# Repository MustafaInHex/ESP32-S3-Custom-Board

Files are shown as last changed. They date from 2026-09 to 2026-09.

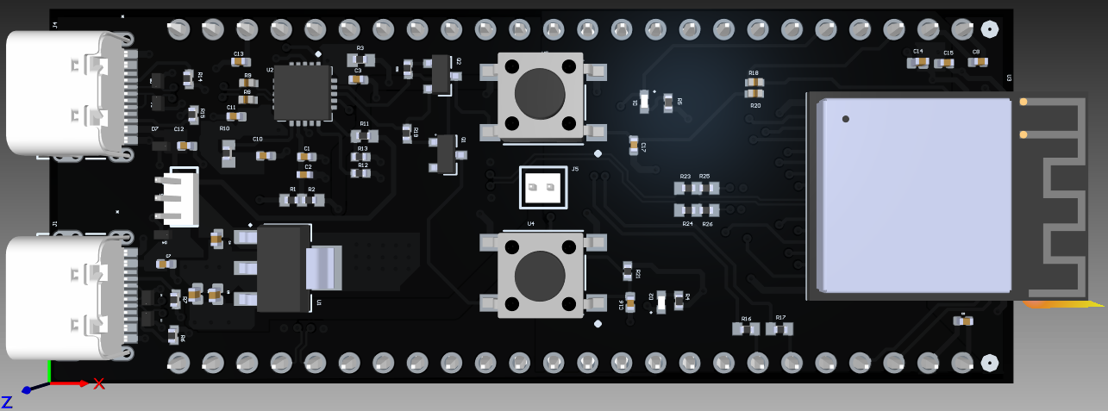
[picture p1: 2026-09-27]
TOP.png

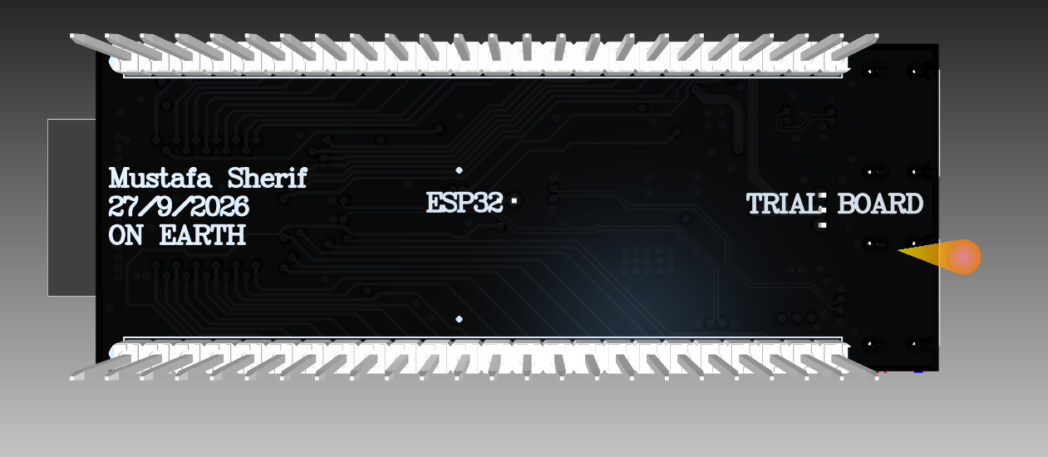
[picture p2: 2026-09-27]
BOTTOM.png

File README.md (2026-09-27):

# ESP32-S3 Dual USB-C Development Board

This repository contains a complete Altium Designer hardware project for a custom ESP32-S3 Mini development board. The design focuses on robust USB connectivity, safe power handling, and standard layout techniques for microcontroller applications.

## Hardware Specifications & Features
* **Microcontroller:** ESP32-S3 Mini module.
* **Dual USB-C Interfaces:**
  * **Port 1 (UART):** Routed through an onboard FTDI USB-to-UART bridge for direct programming, flashing, and serial debugging. Includes auto-reset circuitry using a standard DTR/RTS transistor configuration.
  * **Port 2 (Native):** Direct native USB connection to the ESP32-S3 data pins.
* **Power Management:** Onboard 5V to 3.3V LDO regulation with jumper-selectable routing to easily isolate or select power sources during testing.
* **Signal Integrity & Protection:** Differential pairs for USB data lines are routed for 90Ω impedance. Both USB-C ports feature integrated ESD protection arrays to shield the ICs from voltage spikes.
* **User Interface:** Dedicated tactile switches for Boot and Reset, alongside independent Power and User-programmable status LEDs.
* **Aesthetics:** Custom exposed-copper ENIG (gold) logo implemented via precise solder mask cutouts on the top layer.

## Repository Structure
* **`Altium_Project/`**: Source files including the main project file (`.PrjPcb`), Schematics (`.SchDoc`), PCB Layout (`.PcbDoc`), and Custom Component Libraries (`.SchLib`, `.PcbLib`).
* **`Manufacturing_Outputs/`**: Production-ready `.zip` containing Gerber and NC Drill files, Pick and Place assembly data (`.csv`), and the full Bill of Materials (BOM).
* **`Datasheets/`**: Core technical reference documents, including the ESP32-S3 module datasheet.
* **`3D_Models/`**: STEP files used for the component bodies to ensure accurate 3D visualization and mechanical clearance checking.
* **`Schematic.pdf`**: A high-resolution PDF export of the circuit schematic for immediate browser viewing without requiring Altium Designer.

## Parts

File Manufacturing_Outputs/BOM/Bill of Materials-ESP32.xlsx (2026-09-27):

Description | Designator | Quantity | Manufacturer_Name | Manufacturer_Part_Number | Comment | Footprint
CAP CER 0.1UF 50V X7R 0402 SMD | C1, C3, C7, C8, C9, C10, C11, C12, C13, C15, C17 | 11 |  |  | 100n | CAPC1005X55N
16V 4.7uF X5R 卤20% 0402 Multilayer Ceramic Capacitors MLCC - SMD/SMT ROHS | C2, C4 | 2 |  |  | 4.7U | CAPC1005X70N
CL05A106MP8NUB8-CAP CER 10UF 10V X5R 0402 SMD, CAP CER 10UF 10V X5R 0402 SMD | C5, C6, C14 | 3 |  |  | 10u | CAPC1005X90N
35V 1uF X5R 卤10% 0402 Multilayer Ceramic Capacitors MLCC - SMD/SMT ROHS | C16 | 1 |  |  | 1UF | CAPC1005X65N
LED, GREEN, 60MCD, 573NM, 0402; LED Colour:Green; LED Mounting:SMD; Forward Current If:20mA; Forward Voltage:2V; Wavelength Typ:573nm; Luminous Intensity:60mcd; Viewing Angle:120Â°; Lens Shape:Rectangular; Product Range:WL-SMCC Series; Automotive Qualific | D1, D2 | 2 |  |  | WL-SMCC_0402 | WL-SMCC_0402
TVS DIODE 12VC 3A SOD882 / ESD Suppressor TVS Bi-Dir 5.3V Automotive 2-Pin SOD-882 T/R | D3, D4, D5, D6, D7, D8 | 6 | Littelfuse Inc | AQ3045-01ETG | AQ3045-01ETG | TVS_SOD882_LTF
USB Connector, 16 Contact(s), Female, Right Angle, Surface Mount Terminal, Locking, Receptacle | J1, J4 | 2 |  |  | USBC-2171790001 | USBC-2171790001
KK 254 Breakaway Header, Vertical, 24 Circuits, 0.38µm Gold (Au) Plating, Mating Pin Length 7.49mm, Bag | J2, J3 | 2 |  |  | 22284245 | CONN_SD-42375-001_M295_24_MOL
Pin Header, Board-to-Board, 1.27 mm, 1 Rows, 2 Contacts, Through Hole Straight, FTS Series | J5 | 1 |  |  | SAMTEC-FTS-102-01-X-SJ | SAMTEC-FTS-102-01-X-S
SAMTEC-FTS-103-01-X-S Connector Header Surface Mount 3 position 0.050 (1.27mm) | J6 | 1 |  |  | SAMTEC-FTS-103-01-X-S | SAMTEC-FTS-103-01-X-S
Jumper (Busbar), Jumper Socket, Pin Hdrs; |Harwin M50-1920005 | LINK1, LINK2 | 2 |  |  | Connector header
TRANS NPN 25V 1.5A SOT23-3 / Bipolar (BJT) Transistor NPN 25 V 1.5 A 100MHz 300 mW Surface Mount SOT-23-3 | Q1, Q2 | 2 |  |  | SS8050-G | TRANS_SS8050-G
0 Ohms Jumper 0.063W, 1/16W Chip Resistor 0402 (1005 Metric) Moisture Resistant Thick Film RC0402JR-070RL | R1, R2, R3, R10, R16, R17, R23, R24, R25, R26 | 10 |  |  | 0R | RESC1005X40
1 kOhms Â±1% 0.063W, 1/16W Chip Resistor 0402 (1005 Metric) Moisture Resistant Thick Film | R4, R5 | 2 |  |  | 1K | RESC1005X40N
5.1 kOhms ±1% 0.063W, 1/16W Chip Resistor 0402 (1005 Metric) Automotive AEC-Q200, Moisture Resistant Thick Film | R6, R7, R14, R15 | 4 |  |  | AC0402FR-075K1L | 5k1
62.5mW Thick Film Resistors 50V ±100ppm/℃ ±1% 27Ω 0402 Chip Resistor - Surface Mount ROHS | R8, R9, R18, R20 | 4 | Yageo | RC0402FR-0727RL | 27R | RES_RC0402_YAG
4.7 kOhms ±1% 0.063W, 1/16W Chip Resistor 0402 (1005 Metric) Moisture Resistant Thick Film | R11 | 1 |  |  | 4K7 | RESC1005X40 - duplicate
Res Thick Film 0402 10K Ohm 1% 0.063W(1/16W) ±100ppm/C Pad SMD T/R Automotive AEC-Q200 | R12, R13, R19, R21, R22 | 5 |  |  | 10K | RESC1005X37N
1.5-A, 20-V, low-dropout voltage regulator with reverse current & reverse voltage protection | U1 | 1 |  |  | TL1963A-33DCYR | VREG_TL1963A-33DCYR
IC USB SERIAL FULL UART 20QFN | U2 | 1 |  |  | FT231XQ-R | QFN50P400X400X80-21N
ESP32-S3-MINI-1-N8 RF TXRX MOD BT WIFI PCB TH SMD | U3 | 1 |  |  | ESP32-S3-MINI-1-N8 | ESP32-S3-MINI-1-N8
Switch Tactile N.O SPST Round Button Gull Wing 0.05A 12VDC 100000Cycle 1.57N SMD T/R | U4, U5 | 2 | C&K Components | PTS645SM43SMTR92LFS | PTS645SM43SMTR92LFS | SWITCH_43SMTR92LFS

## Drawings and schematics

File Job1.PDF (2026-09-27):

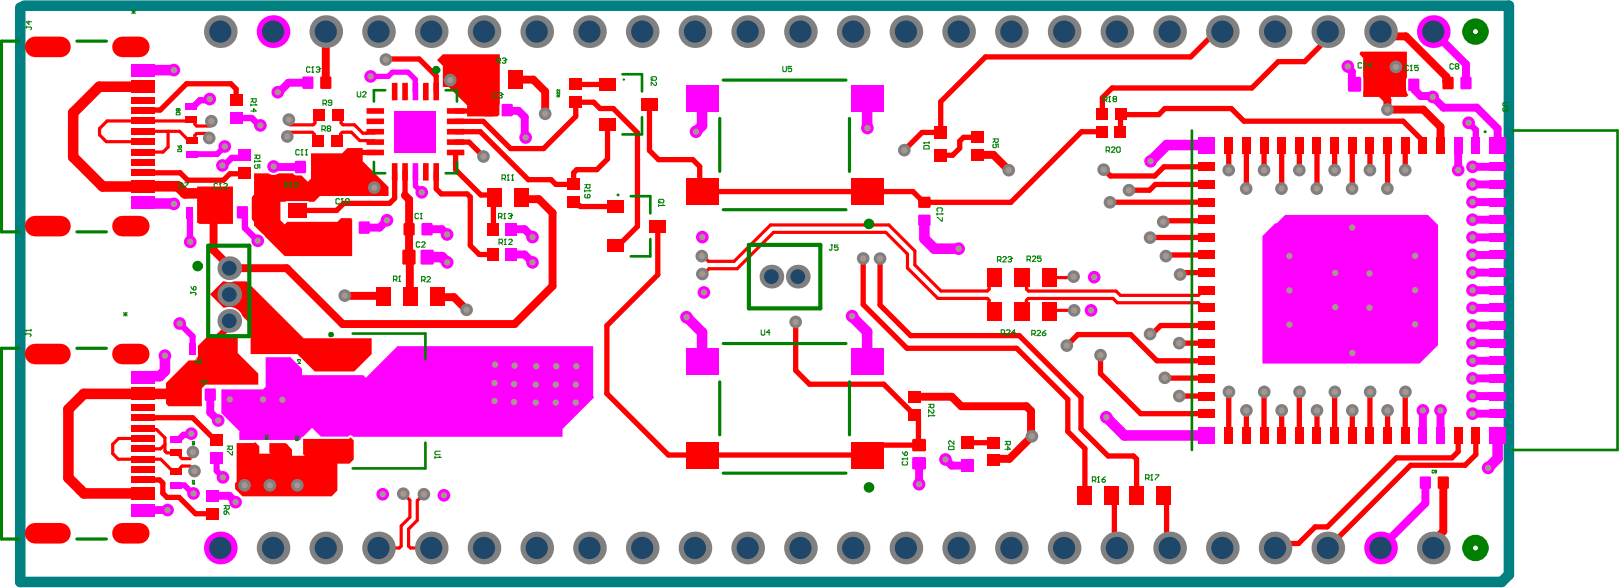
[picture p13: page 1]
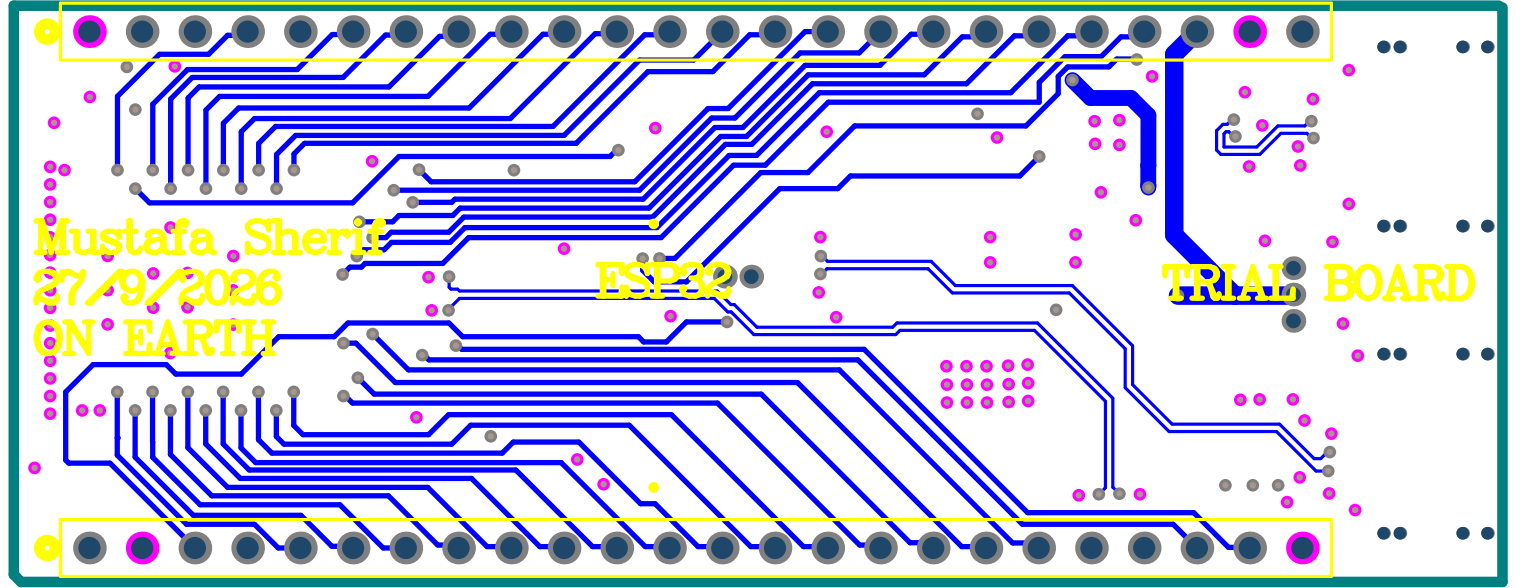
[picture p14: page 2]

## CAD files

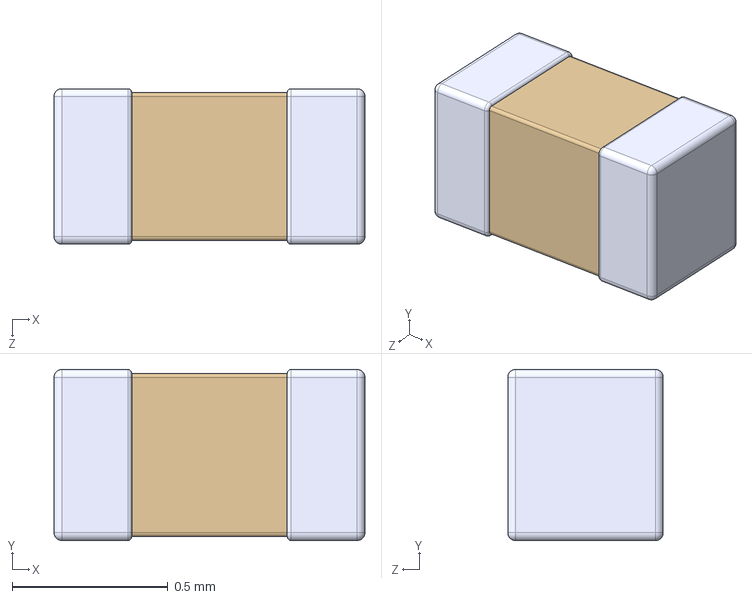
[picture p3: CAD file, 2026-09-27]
3D/CL05B104KB54PNC.STEP
1.00 x 0.55 x 0.5 mm

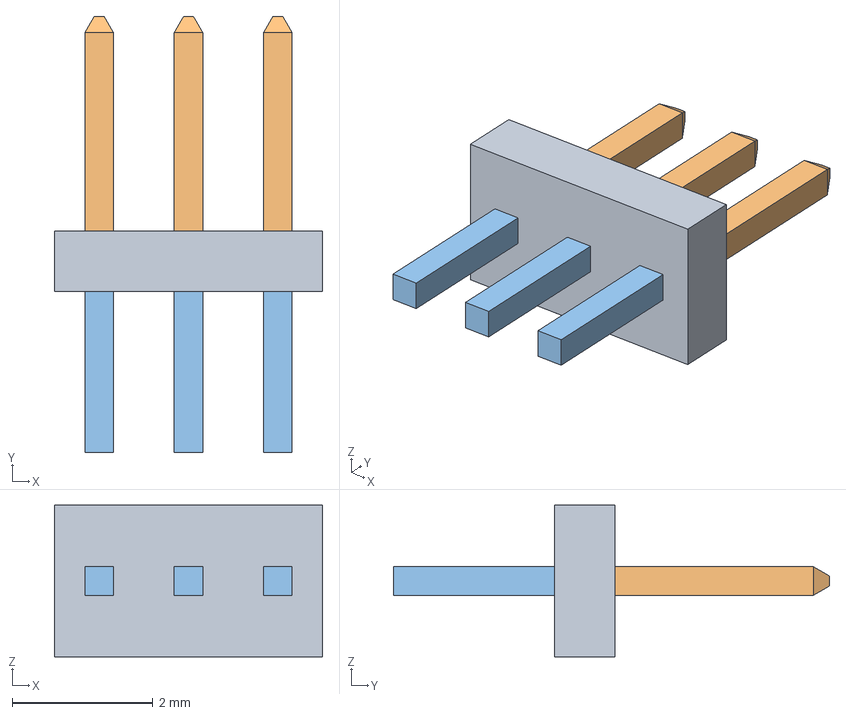
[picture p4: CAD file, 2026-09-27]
3D/FTS-103-01-F-S.stp
3.81 x 6.20 x 2.16 mm
FTS-103-01-F-S_body
FTS-103-01-F-S_pins1
FTS-103-01-F-S_pins2

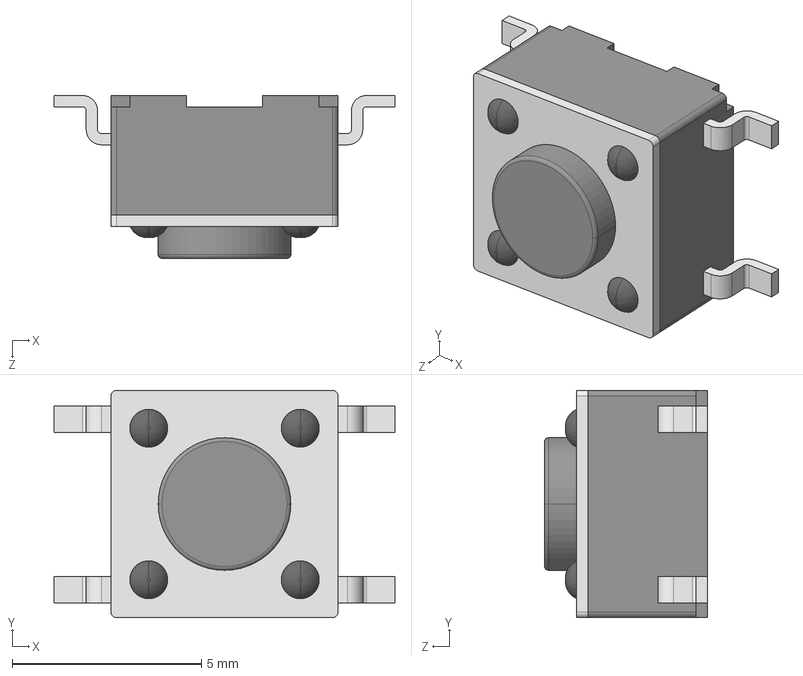
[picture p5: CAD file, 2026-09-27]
3D/PTS645SM43SMTR92LFS.stp
9.00 x 6.00 x 4.30 mm

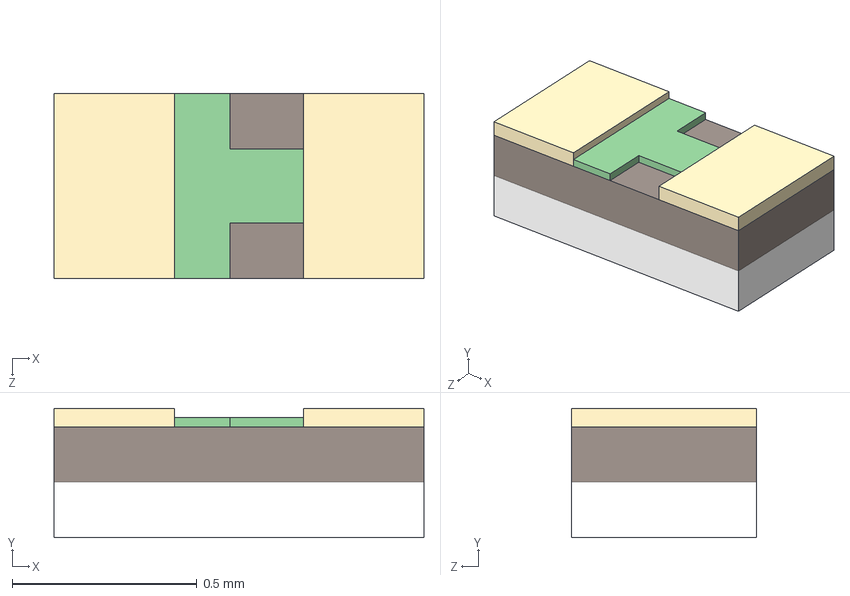
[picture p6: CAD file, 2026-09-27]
3D/VLMG1500-GS08.stp
1.00 x 0.35 x 0.5 mm

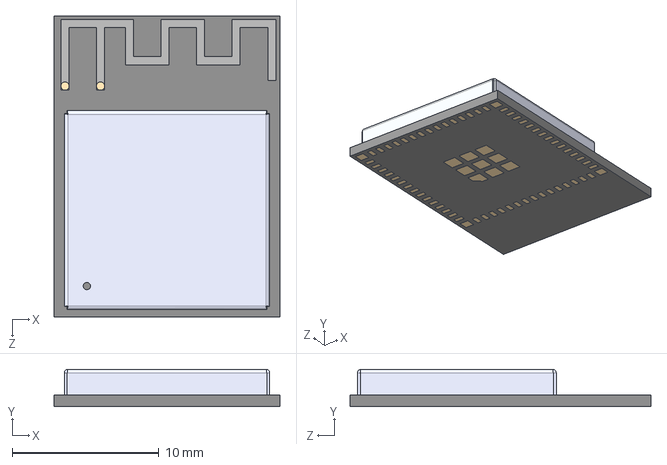
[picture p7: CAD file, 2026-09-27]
3D/ESP32-S3-MINI-1-N8--3DModel-STEP-510211.STEP
15.4 x 2.55 x 20.5 mm

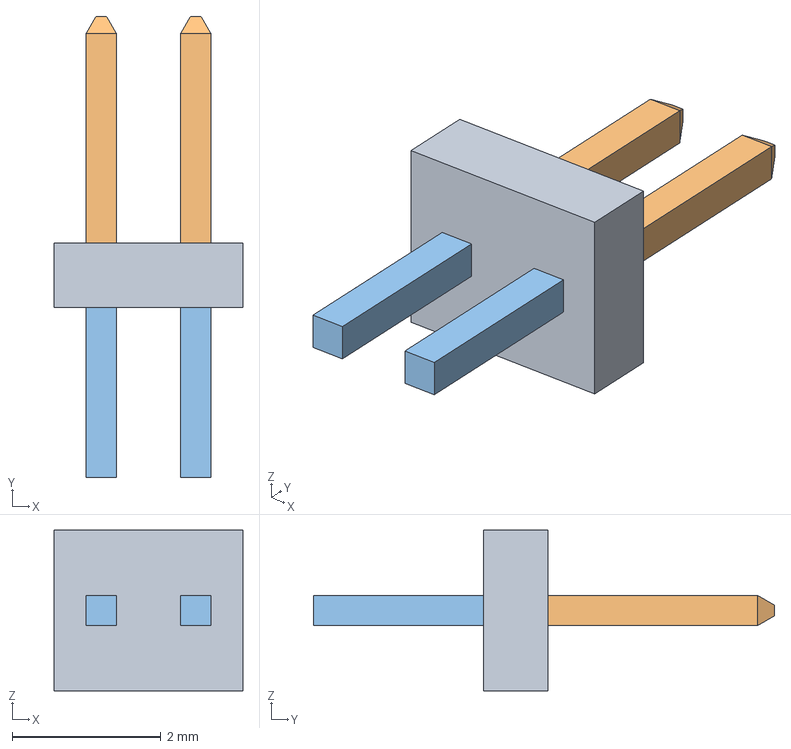
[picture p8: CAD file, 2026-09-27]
3D/FTS-102-01-F-S.stp
2.54 x 6.20 x 2.16 mm
FTS-102-01-F-S_body
FTS-102-01-F-S_pins1
FTS-102-01-F-S_pins2

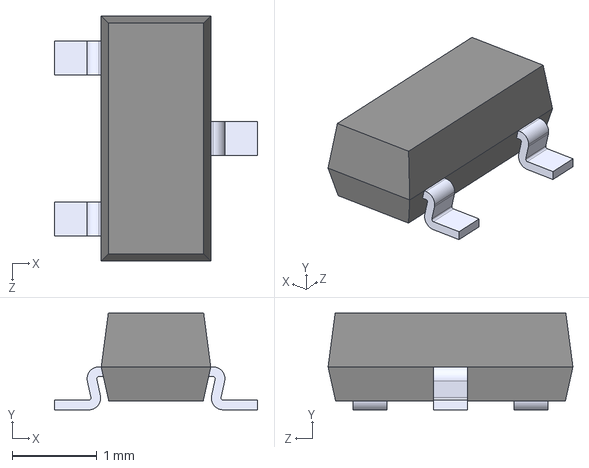
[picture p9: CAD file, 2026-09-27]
3D/SS8050-G--3DModel-STEP-1.STEP
2.40 x 1.14 x 2.90 mm

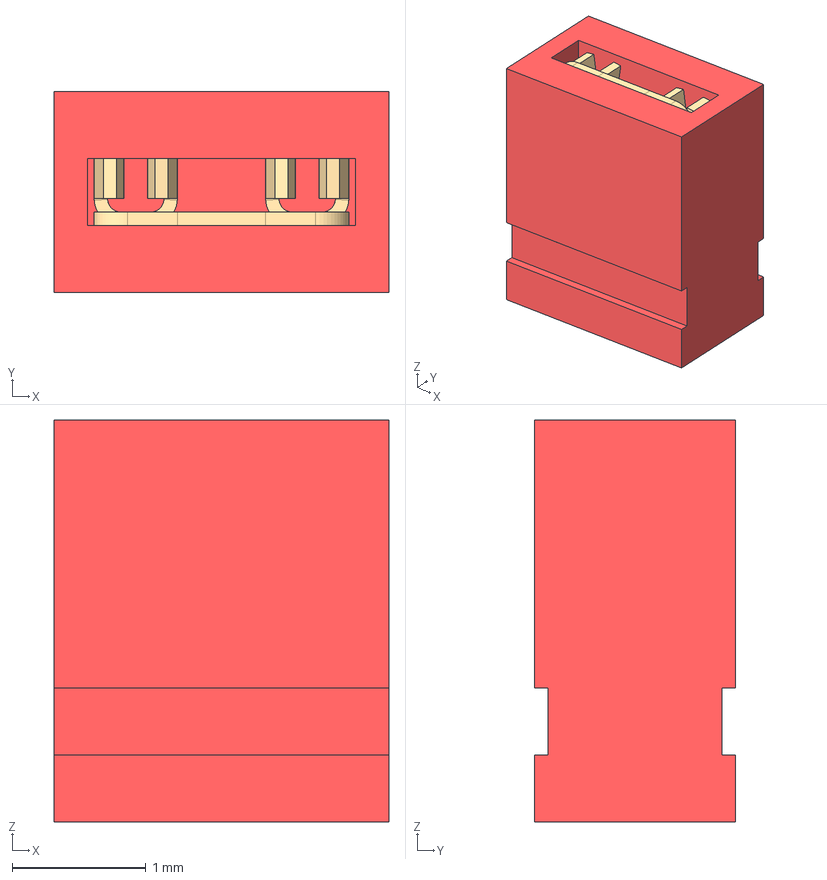
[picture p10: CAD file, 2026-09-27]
3D/M50-1920005.stp
2.50 x 1.50 x 3.00 mm
M50-1920005_MOULD
M50-CONTACT

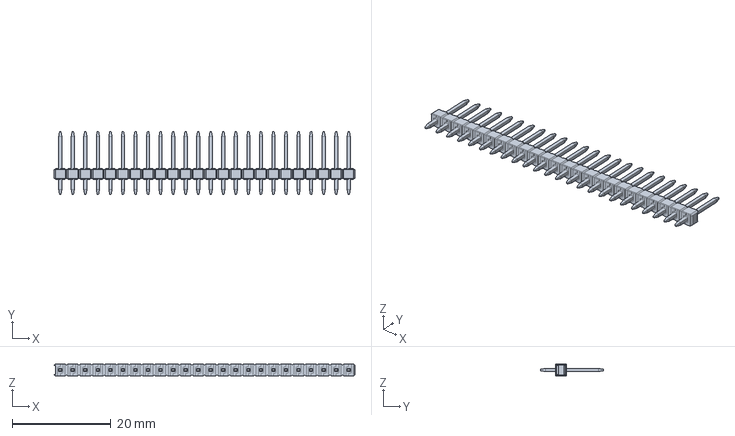
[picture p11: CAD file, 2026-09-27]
3D/022284245.stp
61.0 x 12.8 x 2.49 mm

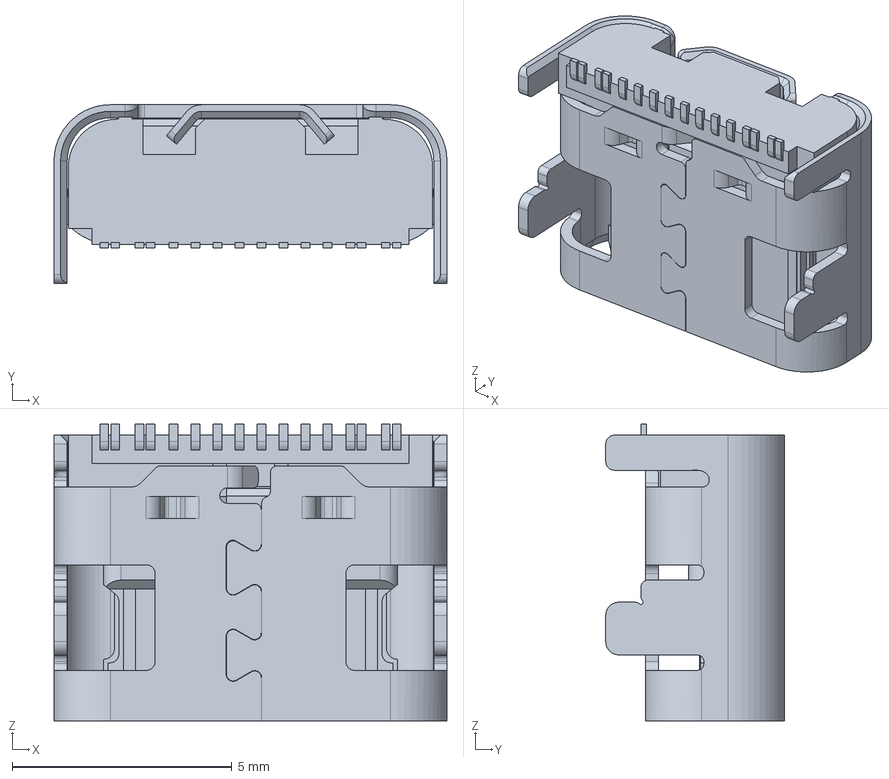
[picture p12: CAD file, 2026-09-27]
3D/2171790001.stp
8.94 x 4.06 x 6.75 mm

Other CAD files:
3D/VLMS1500-GS08.stp

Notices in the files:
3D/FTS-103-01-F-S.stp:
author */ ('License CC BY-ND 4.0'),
